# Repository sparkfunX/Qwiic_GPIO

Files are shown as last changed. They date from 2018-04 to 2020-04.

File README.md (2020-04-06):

SparkX Qwiic GPIO
=======================================

SparkX Qwiic GPIO (https://cdn.sparkfun.com/assets/parts/1/5/1/3/9/16406-Qwiic_GPIO-01.jpg)

[*SparkX Qwiic GPIO (SPX-16443)*](https://www.sparkfun.com/products/16443)

TCA9534 breakout board with Qwiic connectors and easy-to-use latch terminals; no longer screw wires into place! Use this board to add more GPIO pins to your system.

Repository Contents
-------------------

* **/Documents** - Contains datasheets and schematic.pdf
* **/Hardware** - Current .brd and .sch files for product
* **/Software** - Examples to get started with Qwiic GPIO

License Information
-------------------

This product is _**open source**_!

Please review the LICENSE.md file for license information.

If you have any questions or concerns on licensing, please contact technical support on our [SparkFun forums](https://forum.sparkfun.com/viewforum.php?f=152).

Distributed as-is; no warranty is given.

- Your friends at SparkFun.

_<COLLABORATION CREDIT>_

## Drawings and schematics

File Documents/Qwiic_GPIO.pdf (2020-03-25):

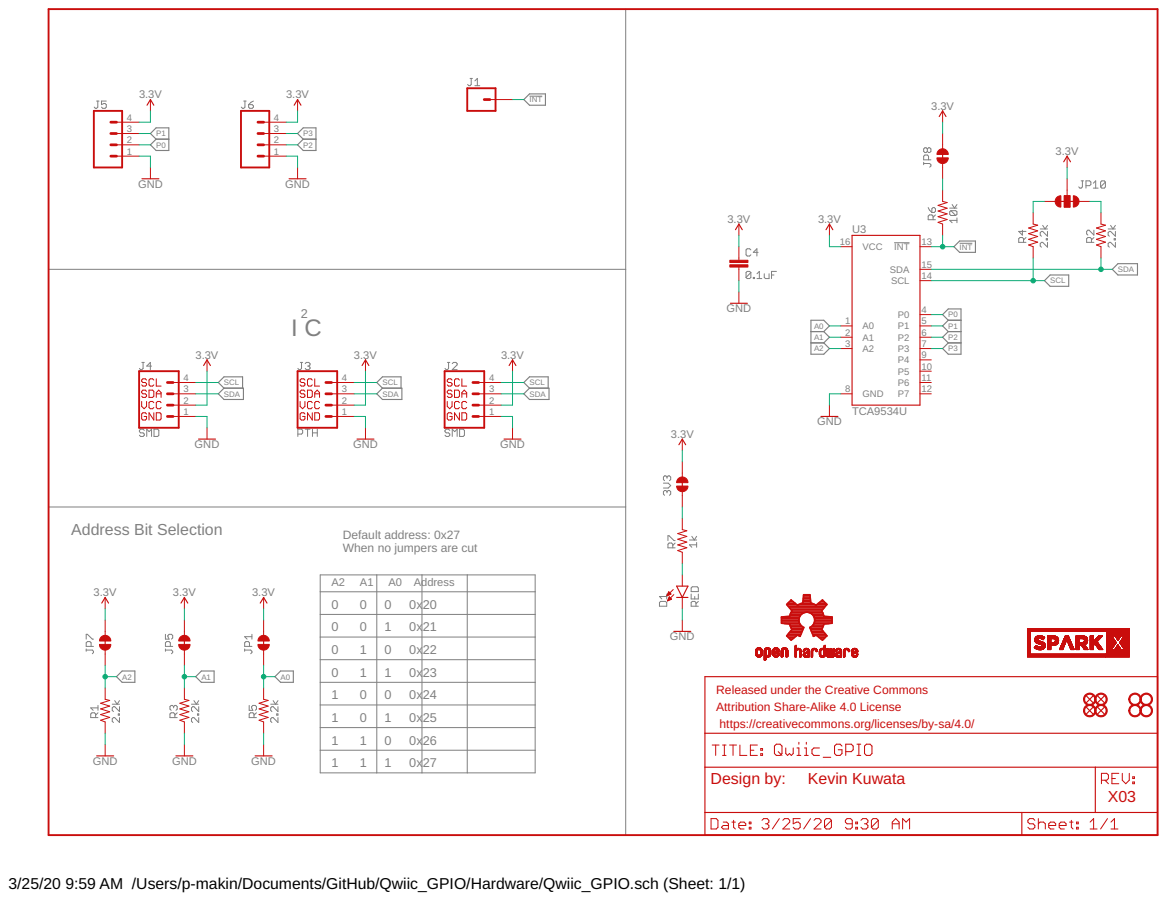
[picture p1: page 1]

Default address: 0x27
When no jumpers are cut

A2 A1 0 | 0 A0 Address 0 0x20

0 0 | 1 0x21
0 1 | 0 0x22
0 1 | 1 0x23
1 0 | 0 0x24
1 0 | 1 0x25
1 1 | 0 0x26
1 1 | 1 0x27

Released under the Creative Commons Attribution Share-Alike 4.0 License

https://creativecommons.org/licenses/by-sa/4.0/

3/25/20 9:59 AM /Users/p-makin/Documents/GitHub/Qwiic_GPIO/Hardware/Qwiic_GPIO.sch (Sheet: 1/1)

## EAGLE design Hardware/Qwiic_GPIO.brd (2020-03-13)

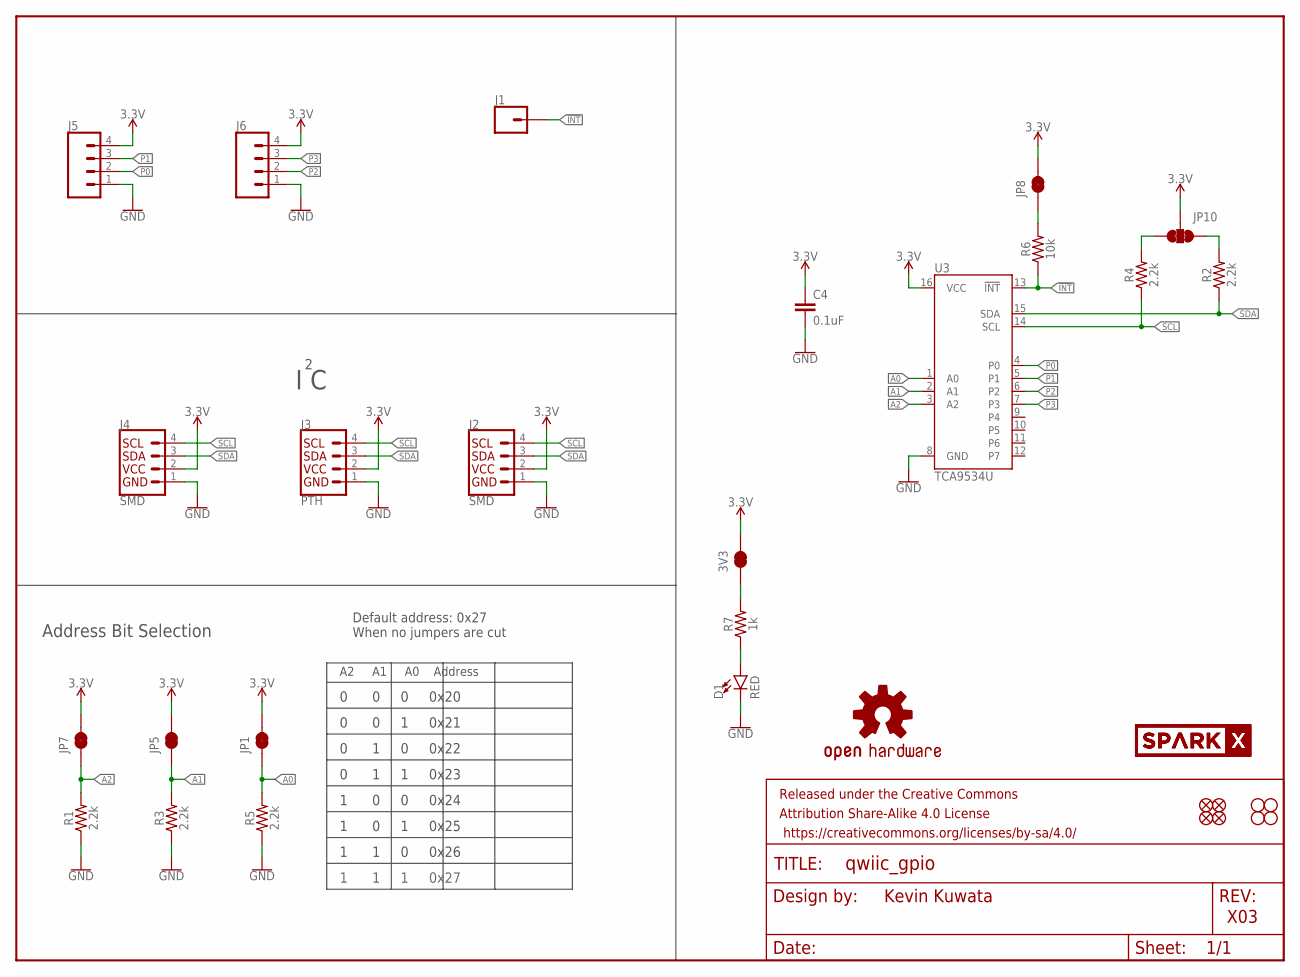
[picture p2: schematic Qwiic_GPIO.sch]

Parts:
3V3: JUMPER-SMT_2_NC_TRACE_SILK; SMT-JUMPER_2_NC_TRACE_SILK
C4: 0.1uF; 0603
D1: RED; LED-0603
FD1, FD2: FIDUCIAL1X2; FIDUCIAL-1X2
FRAME1: FRAME-LETTER; CREATIVE_COMMONS
H1, H2: STAND-OFF
J1: CONN_01PTH_NO_SILK_YES_STOP; 1X01_NO_SILK
J2, J4: SMD; 1X04_1MM_RA
J3: PTH; 1X04_NO_SILK
J5, J6: CONN_04LATCH; LATCHTERMINAL-5MM-4
JP1, JP5, JP7, JP8: JUMPER-SMT_2_NC_TRACE_SILK; SMT-JUMPER_2_NC_TRACE_SILK
JP2, JP6: FIDUCIAL1X2; FIDUCIAL-1X2
JP3, JP4: STAND-OFF
JP10: JUMPER-SMT_3_2-NC_TRACE_SILK; SMT-JUMPER_3_2-NC_TRACE_SILK
LOGO1: OSHW-LOGOMINI; OSHW-LOGO-MINI
R1, R2, R3, R4, R5: 2.2k; 0603
R6: 10k; 0603
R7: 1k; 0603
U3: TCA9534U; 16SOIC
U$1, U$2: SPARKX-LOGO3; SPARKX-SMALL

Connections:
3.3V: 3V3.2, C4.1, J2.2 (VCC), J3.2 (VCC), J4.2 (VCC), J5.4, J6.4, JP1.2, JP5.2, JP7.2, JP8.2, JP10.2, U3.16 (VCC)
!INT: J1.1, R6.1, U3.13 (!INT)
A0: JP1.1, R5.2, U3.1 (A0)
A1: JP5.1, R3.2, U3.2 (A1)
A2: JP7.1, R1.2, U3.3 (A2)
GND: C4.2, D1.C, J2.1 (GND), J3.1 (GND), J4.1 (GND), J5.1, J6.1, R1.1, R3.1, R5.1, U3.8 (GND)
unnamed: JP8.1, R6.2
unnamed: D1.A, R7.1
unnamed: 3V3.1, R7.2
P0: J5.2, U3.4 (P0)
P1: J5.3, U3.5 (P1)
P2: J6.2, U3.6 (P2)
P3: J6.3, U3.7 (P3)
SCL: J2.4 (SCL), J3.4 (SCL), J4.4 (SCL), R4.1, U3.14 (SCL)
SCL_PU1: JP10.1, R2.2
SDA: J2.3 (SDA), J3.3 (SDA), J4.3 (SDA), R2.1, U3.15 (SDA)
SDA_PU1: JP10.3, R4.2

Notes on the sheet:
Kevin Kuwata
X03
I C
Address Bit Selection
A2 A1 A0 Address
0 0 0 0x20
0 0 1 0x21
0 1 0 0x22
0 1 1 0x23
1 0 0 0x24
1 0 1 0x25
1 1 0 0x26
1 1 1 0x27
Default address: 0x27 When no jumpers are cut

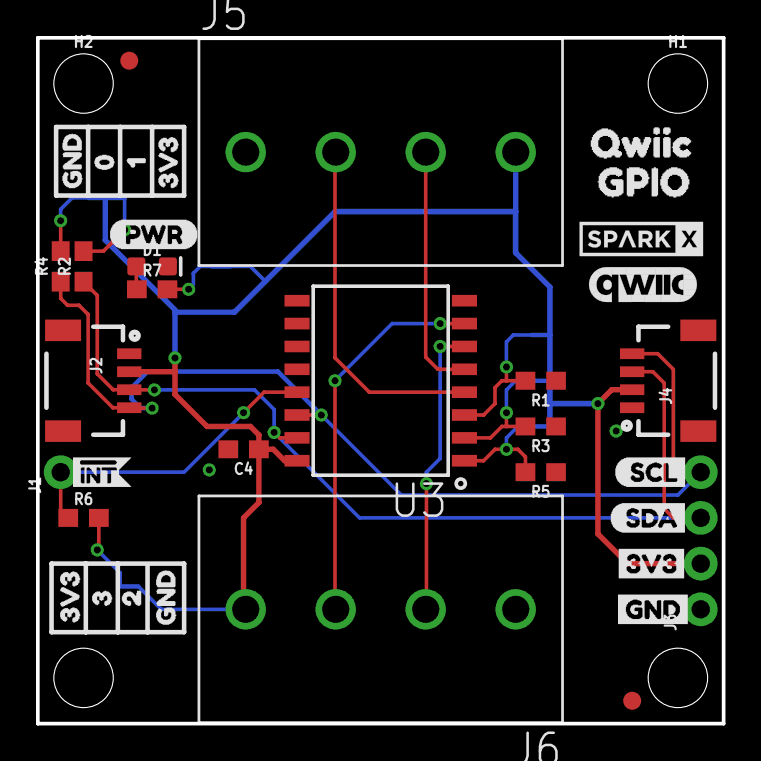
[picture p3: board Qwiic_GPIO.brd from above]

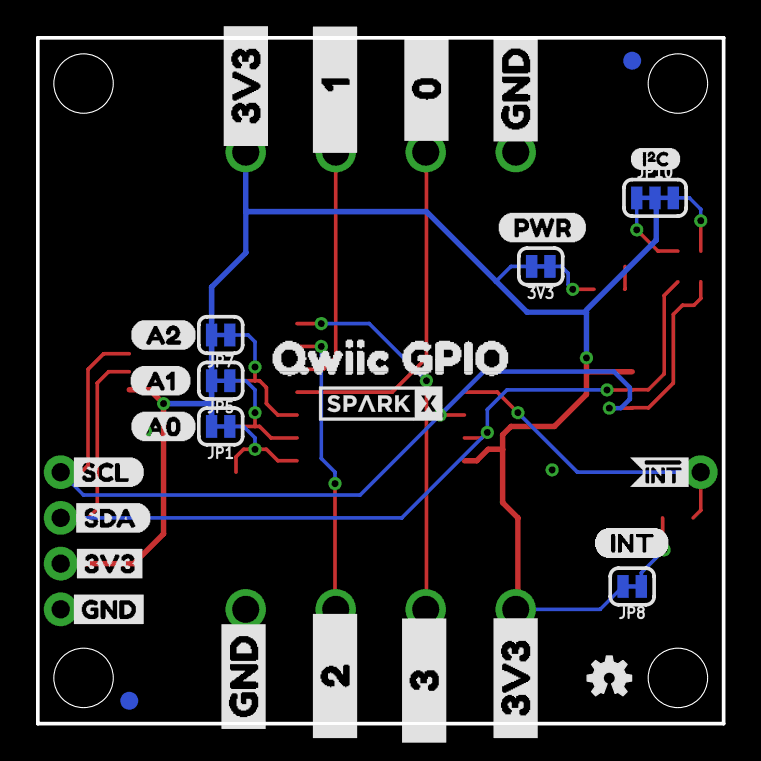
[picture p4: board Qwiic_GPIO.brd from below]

Board: 2 copper layers, 38.1 x 38.1 mm, 72 parts (31 on the bottom side), 17 nets.

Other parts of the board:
U$3, U$26, U$38: 3V33
U$5: A11
U$7, U$25: GND4
U$8: QWIIC_GPIO7
U$9: SCL6
U$10: SDA5
U$11: A00
U$12: A21
U$13, U$22: #INT0
U$20: I_SUPER2_C-()-03
U$21: QWIIC_6MM
U$23: SCL0
U$24: SDA1
U$27: 3V32
U$28: GND1
U$29: 15
U$30, U$31: INT1
U$32: QWIIC1
U$33: 20
U$34: 31
U$35: GND2
U$36: GPIO1
U$37: 04
U$39, U$40: PWR0
U$41: ____0____1
U$42: ____2____3
U$43: ____3____4
U$44: _____1____2
U$45, U$46: GND0
U$47, U$48: _3V3_0

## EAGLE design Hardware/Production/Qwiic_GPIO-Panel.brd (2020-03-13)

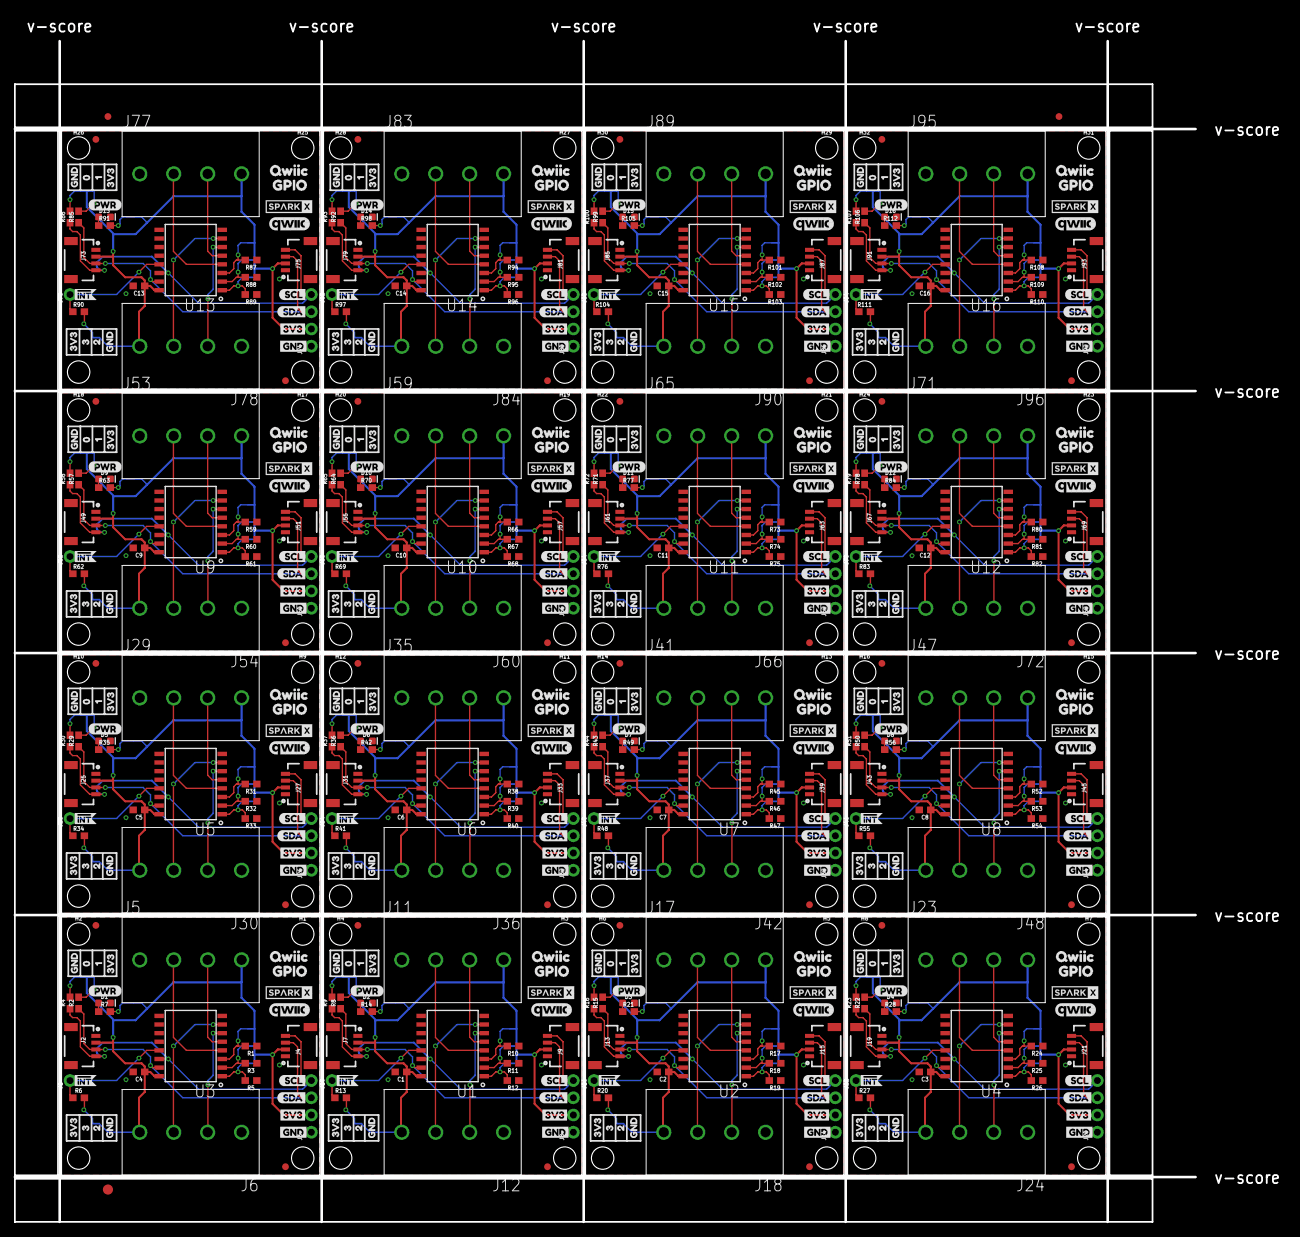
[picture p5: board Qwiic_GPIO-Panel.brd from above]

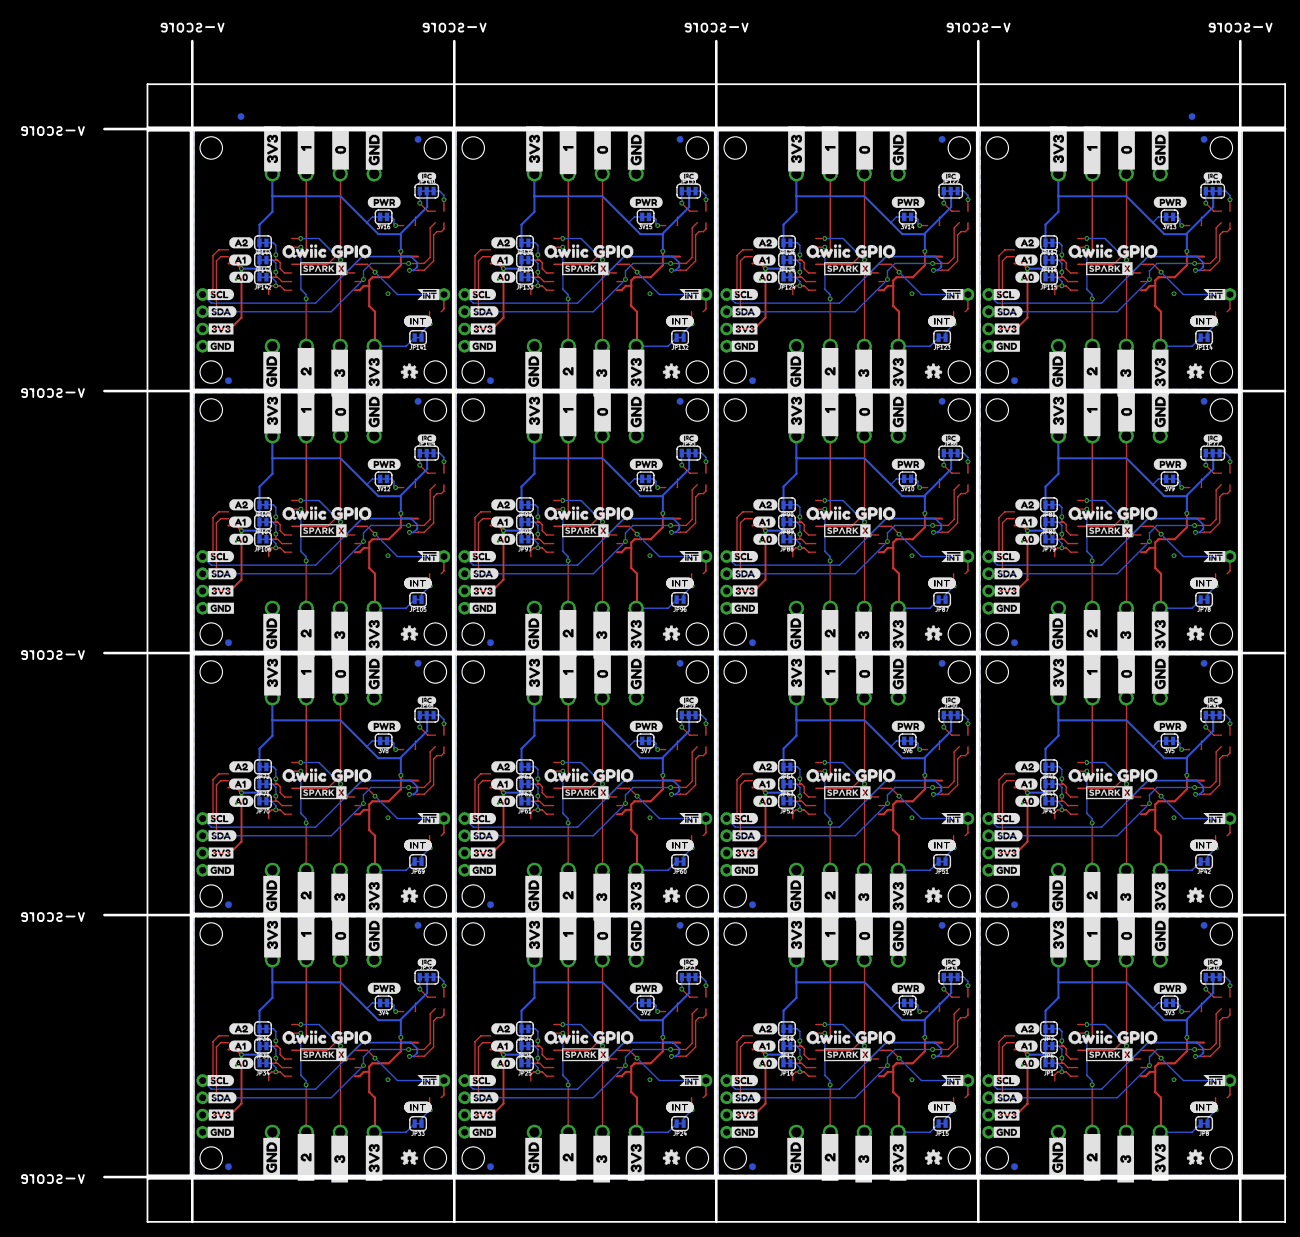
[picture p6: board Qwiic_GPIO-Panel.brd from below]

Board: 2 copper layers, 174.0 x 174.0 mm, 1141 parts (498 on the bottom side), 272 nets.

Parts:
3V1, 3V2, 3V3, 3V4, 3V5, 3V6, 3V7, 3V8, 3V9, 3V10, 3V11, 3V12, 3V13, 3V14, 3V15, 3V16: JUMPER-SMT_2_NC_TRACE_SILK; SMT-JUMPER_2_NC_TRACE_SILK
C1, C2, C3, C4, C5, C6, C7, C8, C9, C10, C11, C12, C13, C14, C15, C16: 0.1uF; 0603
D1, D2, D3, D4, D5, D6, D7, D8, D9, D10, D11, D12, D13, D14, D15, D16: RED; LED-0603
E$1, E$2, E$3, E$4: FIDUCIAL-1X2
E$5: FIDUCIAL-1.5X3
FD1, FD2, FD3, FD4, FD5, FD6, FD7, FD8, FD9, FD10, FD11, FD12, FD13, FD14, FD15, FD16, FD17, FD18, FD19, FD20, FD21, FD22, FD23, FD24, FD25, FD26, FD27, FD28, FD29, FD30, FD31, FD32: FIDUCIAL1X2; FIDUCIAL-1X2
H1, H2, H3, H4, H5, H6, H7, H8, H9, H10, H11, H12, H13, H14, H15, H16, H17, H18, H19, H20, H21, H22, H23, H24, H25, H26, H27, H28, H29, H30, H31, H32: STAND-OFF
J1, J10, J16, J22, J28, J34, J40, J46, J52, J58, J64, J70, J76, J82, J88, J94: 1X01_NO_SILK
J2, J4, J7, J9, J13, J15, J19, J21, J25, J27, J31, J33, J37, J39, J43, J45, J49, J51, J55, J57, J61, J63, J67, J69, J73, J75, J79, J81, J85, J87, J91, J93: SMD; 1X04_1MM_RA
J3, J8, J14, J20, J26, J32, J38, J44, J50, J56, J62, J68, J74, J80, J86, J92: PTH; 1X04_NO_SILK
J5, J6, J11, J12, J17, J18, J23, J24, J29, J30, J35, J36, J41, J42, J47, J48, J53, J54, J59, J60, J65, J66, J71, J72, J77, J78, J83, J84, J89, J90, J95, J96: LATCHTERMINAL-5MM-4
JP1, JP5, JP7, JP16, JP17, JP18, JP25, JP26, JP27, JP34, JP35, JP36, JP43, JP44, JP45, JP52, JP53, JP54, JP61, JP62, JP63, JP70, JP71, JP72, JP79, JP80, JP81, JP88, JP89, JP90, JP97, JP98, JP99, JP106, JP107, JP108, JP115, JP116, JP117, JP124, JP125, JP126, JP133, JP134, JP135, JP142, JP143, JP144: SMT-JUMPER_2_NC_TRACE_SILK
JP2, JP6, JP12, JP13, JP21, JP22, JP30, JP31, JP39, JP40, JP48, JP49, JP57, JP58, JP66, JP67, JP75, JP76, JP84, JP85, JP93, JP94, JP102, JP103, JP111, JP112, JP120, JP121, JP129, JP130, JP138, JP139: FIDUCIAL1X2; FIDUCIAL-1X2
JP3, JP4, JP9, JP11, JP19, JP20, JP28, JP29, JP37, JP38, JP46, JP47, JP55, JP56, JP64, JP65, JP73, JP74, JP82, JP83, JP91, JP92, JP100, JP101, JP109, JP110, JP118, JP119, JP127, JP128, JP136, JP137: STAND-OFF
JP8, JP15, JP24, JP33, JP42, JP51, JP60, JP69, JP78, JP87, JP96, JP105, JP114, JP123, JP132, JP141: JUMPER-SMT_2_NC_TRACE_SILK; SMT-JUMPER_2_NC_TRACE_SILK
JP10, JP14, JP23, JP32, JP41, JP50, JP59, JP68, JP77, JP86, JP95, JP104, JP113, JP122, JP131, JP140: JUMPER-SMT_3_2-NC_TRACE_SILK; SMT-JUMPER_3_2-NC_TRACE_SILK
LOGO1, LOGO2, LOGO3, LOGO4, LOGO5, LOGO6, LOGO7, LOGO8, LOGO9, LOGO10, LOGO11, LOGO12, LOGO13, LOGO14, LOGO15, LOGO16: OSHW-LOGOMINI; OSHW-LOGO-MINI
R1, R2, R3, R4, R5, R8, R9, R10, R11, R12, R15, R16, R17, R18, R19, R22, R23, R24, R25, R26, R29, R30, R31, R32, R33, R36, R37, R38, R39, R40, R43, R44, R45, R46, R47, R50, R51, R52, R53, R54, R57, R58, R59, R60, R61, R64, R65, R66, R67, R68, R71, R72, R73, R74, R75, R78, R79, R80, R81, R82, R85, R86, R87, R88, R89, R92, R93, R94, R95, R96, R99, R100, R101, R102, R103, R106, R107, R108, R109, R110: 2.2k; 0603
R6, R13, R20, R27, R34, R41, R48, R55, R62, R69, R76, R83, R90, R97, R104, R111: 10k; 0603
R7, R14, R21, R28, R35, R42, R49, R56, R63, R70, R77, R84, R91, R98, R105, R112: 1k; 0603
U1, U2, U3, U4, U5, U6, U7, U8, U9, U10, U11, U12, U13, U14, U15, U16: TCA9534U; 16SOIC
U$1, U$2, U$4, U$6, U$81, U$82, U$121, U$122, U$161, U$162, U$201, U$202, U$241, U$242, U$281, U$282, U$321, U$322, U$361, U$362, U$401, U$402, U$441, U$442, U$481, U$482, U$521, U$522, U$561, U$562, U$601, U$602: SPARKX-LOGO3; SPARKX-SMALL
U$3, U$14, U$26, U$38, U$56, U$66, U$83, U$96, U$106, U$123, U$136, U$146, U$163, U$176, U$186, U$203, U$216, U$226, U$243, U$256, U$266, U$283, U$296, U$306, U$323, U$336, U$346, U$363, U$376, U$386, U$403, U$416, U$426, U$443, U$456, U$466, U$483, U$496, U$506, U$523, U$536, U$546, U$563, U$576, U$586, U$603, U$616, U$626: 3V33
U$5, U$15, U$84, U$124, U$164, U$204, U$244, U$284, U$324, U$364, U$404, U$444, U$484, U$524, U$564, U$604: A11
U$7, U$16, U$25, U$55, U$85, U$95, U$125, U$135, U$165, U$175, U$205, U$215, U$245, U$255, U$285, U$295, U$325, U$335, U$365, U$375, U$405, U$415, U$445, U$455, U$485, U$495, U$525, U$535, U$565, U$575, U$605, U$615: GND4
U$8, U$17, U$86, U$126, U$166, U$206, U$246, U$286, U$326, U$366, U$406, U$446, U$486, U$526, U$566, U$606: QWIIC_GPIO7
U$9, U$18, U$87, U$127, U$167, U$207, U$247, U$287, U$327, U$367, U$407, U$447, U$487, U$527, U$567, U$607: SCL6
U$10, U$19, U$88, U$128, U$168, U$208, U$248, U$288, U$328, U$368, U$408, U$448, U$488, U$528, U$568, U$608: SDA5
U$11, U$49, U$89, U$129, U$169, U$209, U$249, U$289, U$329, U$369, U$409, U$449, U$489, U$529, U$569, U$609: A00
U$12, U$50, U$90, U$130, U$170, U$210, U$250, U$290, U$330, U$370, U$410, U$450, U$490, U$530, U$570, U$610: A21
U$13, U$22, U$57, U$58, U$97, U$98, U$137, U$138, U$177, U$178, U$217, U$218, U$257, U$258, U$297, U$298, U$337, U$338, U$377, U$378, U$417, U$418, U$457, U$458, U$497, U$498, U$537, U$538, U$577, U$578, U$617, U$618: #INT0
U$20, U$51, U$91, U$131, U$171, U$211, U$251, U$291, U$331, U$371, U$411, U$451, U$491, U$531, U$571, U$611: I_SUPER2_C-()-03
U$21, U$52, U$92, U$132, U$172, U$212, U$252, U$292, U$332, U$372, U$412, U$452, U$492, U$532, U$572, U$612: QWIIC_6MM
U$23, U$53, U$93, U$133, U$173, U$213, U$253, U$293, U$333, U$373, U$413, U$453, U$493, U$533, U$573, U$613: SCL0
U$24, U$54, U$94, U$134, U$174, U$214, U$254, U$294, U$334, U$374, U$414, U$454, U$494, U$534, U$574, U$614: SDA1
U$27, U$67, U$107, U$147, U$187, U$227, U$267, U$307, U$347, U$387, U$427, U$467, U$507, U$547, U$587, U$627: 3V32
U$28, U$68, U$108, U$148, U$188, U$228, U$268, U$308, U$348, U$388, U$428, U$468, U$508, U$548, U$588, U$628: GND1
U$29, U$62, U$102, U$142, U$182, U$222, U$262, U$302, U$342, U$382, U$422, U$462, U$502, U$542, U$582, U$622: 15
U$30, U$31, U$69, U$70, U$109, U$110, U$149, U$150, U$189, U$190, U$229, U$230, U$269, U$270, U$309, U$310, U$349, U$350, U$389, U$390, U$429, U$430, U$469, U$470, U$509, U$510, U$549, U$550, U$589, U$590, U$629, U$630: INT1
U$32, U$59, U$99, U$139, U$179, U$219, U$259, U$299, U$339, U$379, U$419, U$459, U$499, U$539, U$579, U$619: QWIIC1
U$33, U$63, U$103, U$143, U$183, U$223, U$263, U$303, U$343, U$383, U$423, U$463, U$503, U$543, U$583, U$623: 20
U$34, U$64, U$104, U$144, U$184, U$224, U$264, U$304, U$344, U$384, U$424, U$464, U$504, U$544, U$584, U$624: 31
U$35, U$65, U$105, U$145, U$185, U$225, U$265, U$305, U$345, U$385, U$425, U$465, U$505, U$545, U$585, U$625: GND2
U$36, U$60, U$100, U$140, U$180, U$220, U$260, U$300, U$340, U$380, U$420, U$460, U$500, U$540, U$580, U$620: GPIO1
U$37, U$61, U$101, U$141, U$181, U$221, U$261, U$301, U$341, U$381, U$421, U$461, U$501, U$541, U$581, U$621: 04
U$39, U$40, U$71, U$72, U$111, U$112, U$151, U$152, U$191, U$192, U$231, U$232, U$271, U$272, U$311, U$312, U$351, U$352, U$391, U$392, U$431, U$432, U$471, U$472, U$511, U$512, U$551, U$552, U$591, U$592, U$631, U$632: PWR0
U$41, U$73, U$113, U$153, U$193, U$233, U$273, U$313, U$353, U$393, U$433, U$473, U$513, U$553, U$593, U$633: ____0____1
U$42, U$74, U$114, U$154, U$194, U$234, U$274, U$314, U$354, U$394, U$434, U$474, U$514, U$554, U$594, U$634: ____2____3
U$43, U$75, U$115, U$155, U$195, U$235, U$275, U$315, U$355, U$395, U$435, U$475, U$515, U$555, U$595, U$635: ____3____4
U$44, U$76, U$116, U$156, U$196, U$236, U$276, U$316, U$356, U$396, U$436, U$476, U$516, U$556, U$596, U$636: _____1____2
U$45, U$46, U$77, U$78, U$117, U$118, U$157, U$158, U$197, U$198, U$237, U$238, U$277, U$278, U$317, U$318, U$357, U$358, U$397, U$398, U$437, U$438, U$477, U$478, U$517, U$518, U$557, U$558, U$597, U$598, U$637, U$638: GND0
U$47, U$48, U$79, U$80, U$119, U$120, U$159, U$160, U$199, U$200, U$239, U$240, U$279, U$280, U$319, U$320, U$359, U$360, U$399, U$400, U$439, U$440, U$479, U$480, U$519, U$520, U$559, U$560, U$599, U$600, U$639, U$640: _3V3_0

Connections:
3.3V: 3V3.2, C4.1, J2.2, J3.2, J4.2, J5.4, J6.4, JP1.2, JP5.2, JP7.2, JP8.2, JP10.2, U3.16
3.3V1: 3V1.2, C1.1, J7.2, J8.2, J9.2, J11.4, J12.4, JP14.2, JP15.2, JP16.2, JP17.2, JP18.2, U1.16
3.3V2: 3V2.2, C2.1, J13.2, J14.2, J15.2, J17.4, J18.4, JP23.2, JP24.2, JP25.2, JP26.2, JP27.2, U2.16
3.3V3: 3V4.2, C3.1, J19.2, J20.2, J21.2, J23.4, J24.4, JP32.2, JP33.2, JP34.2, JP35.2, JP36.2, U4.16
3.3V4: 3V5.2, C5.1, J25.2, J26.2, J27.2, J29.4, J30.4, JP41.2, JP42.2, JP43.2, JP44.2, JP45.2, U5.16
3.3V5: 3V6.2, C6.1, J31.2, J32.2, J33.2, J35.4, J36.4, JP50.2, JP51.2, JP52.2, JP53.2, JP54.2, U6.16
3.3V6: 3V7.2, C7.1, J37.2, J38.2, J39.2, J41.4, J42.4, JP59.2, JP60.2, JP61.2, JP62.2, JP63.2, U7.16
3.3V7: 3V8.2, C8.1, J43.2, J44.2, J45.2, J47.4, J48.4, JP68.2, JP69.2, JP70.2, JP71.2, JP72.2, U8.16
3.3V8: 3V9.2, C9.1, J49.2, J50.2, J51.2, J53.4, J54.4, JP77.2, JP78.2, JP79.2, JP80.2, JP81.2, U9.16
3.3V9: 3V10.2, C10.1, J55.2, J56.2, J57.2, J59.4, J60.4, JP86.2, JP87.2, JP88.2, JP89.2, JP90.2, U10.16
3.3V10: 3V11.2, C11.1, J61.2, J62.2, J63.2, J65.4, J66.4, JP95.2, JP96.2, JP97.2, JP98.2, JP99.2, U11.16
3.3V11: 3V12.2, C12.1, J67.2, J68.2, J69.2, J71.4, J72.4, JP104.2, JP105.2, JP106.2, JP107.2, JP108.2, U12.16
3.3V12: 3V13.2, C13.1, J73.2, J74.2, J75.2, J77.4, J78.4, JP113.2, JP114.2, JP115.2, JP116.2, JP117.2, U13.16
3.3V13: 3V14.2, C14.1, J79.2, J80.2, J81.2, J83.4, J84.4, JP122.2, JP123.2, JP124.2, JP125.2, JP126.2, U14.16
3.3V14: 3V15.2, C15.1, J85.2, J86.2, J87.2, J89.4, J90.4, JP131.2, JP132.2, JP133.2, JP134.2, JP135.2, U15.16
3.3V15: 3V16.2, C16.1, J91.2, J92.2, J93.2, J95.4, J96.4, JP140.2, JP141.2, JP142.2, JP143.2, JP144.2, U16.16
!INT: J1.1, R6.1, U3.13
!INT1: J10.1, R13.1, U1.13
!INT2: J16.1, R20.1, U2.13
!INT3: J22.1, R27.1, U4.13
!INT4: J28.1, R34.1, U5.13
!INT5: J34.1, R41.1, U6.13
!INT6: J40.1, R48.1, U7.13
!INT7: J46.1, R55.1, U8.13
!INT8: J52.1, R62.1, U9.13
!INT9: J58.1, R69.1, U10.13
!INT10: J64.1, R76.1, U11.13
!INT11: J70.1, R83.1, U12.13
!INT12: J76.1, R90.1, U13.13
!INT13: J82.1, R97.1, U14.13
!INT14: J88.1, R104.1, U15.13
!INT15: J94.1, R111.1, U16.13
A0: JP1.1, R5.2, U3.1
A1: JP5.1, R3.2, U3.2
A2: JP7.1, R1.2, U3.3
A3: JP16.1, R12.2, U1.1
A4: JP17.1, R11.2, U1.2
A5: JP18.1, R10.2, U1.3
A6: JP25.1, R19.2, U2.1
A7: JP26.1, R18.2, U2.2
A8: JP27.1, R17.2, U2.3
A9: JP34.1, R26.2, U4.1
A10: JP35.1, R25.2, U4.2
A11: JP36.1, R24.2, U4.3
A12: JP43.1, R33.2, U5.1
A13: JP44.1, R32.2, U5.2
A14: JP45.1, R31.2, U5.3
A15: JP52.1, R40.2, U6.1
A16: JP53.1, R39.2, U6.2
A17: JP54.1, R38.2, U6.3
A18: JP61.1, R47.2, U7.1
A19: JP62.1, R46.2, U7.2
A20: JP63.1, R45.2, U7.3
A21: JP70.1, R54.2, U8.1
A22: JP71.1, R53.2, U8.2
A23: JP72.1, R52.2, U8.3
A24: JP79.1, R61.2, U9.1
A25: JP80.1, R60.2, U9.2
A26: JP81.1, R59.2, U9.3
A27: JP88.1, R68.2, U10.1
A28: JP89.1, R67.2, U10.2
A29: JP90.1, R66.2, U10.3
A30: JP97.1, R75.2, U11.1
A31: JP98.1, R74.2, U11.2
A32: JP99.1, R73.2, U11.3
A33: JP106.1, R82.2, U12.1
A34: JP107.1, R81.2, U12.2
A35: JP108.1, R80.2, U12.3
A36: JP115.1, R89.2, U13.1
A37: JP116.1, R88.2, U13.2
A38: JP117.1, R87.2, U13.3
A39: JP124.1, R96.2, U14.1
A40: JP125.1, R95.2, U14.2
A41: JP126.1, R94.2, U14.3
A42: JP133.1, R103.2, U15.1
A43: JP134.1, R102.2, U15.2
A44: JP135.1, R101.2, U15.3
A45: JP142.1, R110.2, U16.1
A46: JP143.1, R109.2, U16.2
A47: JP144.1, R108.2, U16.3
GND: C4.2, D1.C, J2.1, J3.1, J4.1, J5.1, J6.1, R1.1, R3.1, R5.1, U3.8
GND1: C1.2, D2.C, J7.1, J8.1, J9.1, J11.1, J12.1, R10.1, R11.1, R12.1, U1.8
GND2: C2.2, D3.C, J13.1, J14.1, J15.1, J17.1, J18.1, R17.1, R18.1, R19.1, U2.8
GND3: C3.2, D4.C, J19.1, J20.1, J21.1, J23.1, J24.1, R24.1, R25.1, R26.1, U4.8
GND4: C5.2, D5.C, J25.1, J26.1, J27.1, J29.1, J30.1, R31.1, R32.1, R33.1, U5.8
GND5: C6.2, D6.C, J31.1, J32.1, J33.1, J35.1, J36.1, R38.1, R39.1, R40.1, U6.8
GND6: C7.2, D7.C, J37.1, J38.1, J39.1, J41.1, J42.1, R45.1, R46.1, R47.1, U7.8
GND7: C8.2, D8.C, J43.1, J44.1, J45.1, J47.1, J48.1, R52.1, R53.1, R54.1, U8.8
GND8: C9.2, D9.C, J49.1, J50.1, J51.1, J53.1, J54.1, R59.1, R60.1, R61.1, U9.8
GND9: C10.2, D10.C, J55.1, J56.1, J57.1, J59.1, J60.1, R66.1, R67.1, R68.1, U10.8
GND10: C11.2, D11.C, J61.1, J62.1, J63.1, J65.1, J66.1, R73.1, R74.1, R75.1, U11.8
GND11: C12.2, D12.C, J67.1, J68.1, J69.1, J71.1, J72.1, R80.1, R81.1, R82.1, U12.8
GND12: C13.2, D13.C, J73.1, J74.1, J75.1, J77.1, J78.1, R87.1, R88.1, R89.1, U13.8
GND13: C14.2, D14.C, J79.1, J80.1, J81.1, J83.1, J84.1, R94.1, R95.1, R96.1, U14.8
GND14: C15.2, D15.C, J85.1, J86.1, J87.1, J89.1, J90.1, R101.1, R102.1, R103.1, U15.8
GND15: C16.2, D16.C, J91.1, J92.1, J93.1, J95.1, J96.1, R108.1, R109.1, R110.1, U16.8
unnamed: JP8.1, R6.2
unnamed: D1.A, R7.1
unnamed: 3V3.1, R7.2
unnamed: JP15.1, R13.2
unnamed: D2.A, R14.1
unnamed: 3V1.1, R14.2
unnamed: JP24.1, R20.2
unnamed: D3.A, R21.1
unnamed: 3V2.1, R21.2
unnamed: JP33.1, R27.2
unnamed: D4.A, R28.1
unnamed: 3V4.1, R28.2
unnamed: JP42.1, R34.2
unnamed: D5.A, R35.1
unnamed: 3V5.1, R35.2
unnamed: JP51.1, R41.2
unnamed: D6.A, R42.1
unnamed: 3V6.1, R42.2
unnamed: JP60.1, R48.2
unnamed: D7.A, R49.1
unnamed: 3V7.1, R49.2
unnamed: JP69.1, R55.2
unnamed: D8.A, R56.1
unnamed: 3V8.1, R56.2
unnamed: JP78.1, R62.2
unnamed: D9.A, R63.1
unnamed: 3V9.1, R63.2
unnamed: JP87.1, R69.2
unnamed: D10.A, R70.1
unnamed: 3V10.1, R70.2
unnamed: JP96.1, R76.2
unnamed: D11.A, R77.1
unnamed: 3V11.1, R77.2
unnamed: JP105.1, R83.2
unnamed: D12.A, R84.1
unnamed: 3V12.1, R84.2
unnamed: JP114.1, R90.2
unnamed: D13.A, R91.1
unnamed: 3V13.1, R91.2
unnamed: JP123.1, R97.2
unnamed: D14.A, R98.1
unnamed: 3V14.1, R98.2
unnamed: JP132.1, R104.2
unnamed: D15.A, R105.1
unnamed: 3V15.1, R105.2
unnamed: JP141.1, R111.2
unnamed: D16.A, R112.1
unnamed: 3V16.1, R112.2
P0: J5.2, U3.4
P1: J5.3, U3.5
P2: J6.2, U3.6
P3: J6.3, U3.7
P4: J11.2, U1.4
P5: J12.2, U1.6
P6: J12.3, U1.7
P7: J11.3, U1.5
P8: J17.2, U2.4
P9: J18.2, U2.6
P10: J18.3, U2.7
P11: J17.3, U2.5
P12: J23.2, U4.4
P13: J24.2, U4.6
P14: J24.3, U4.7
P15: J23.3, U4.5
P16: J29.2, U5.4
P17: J30.2, U5.6
P18: J30.3, U5.7
P19: J29.3, U5.5
P20: J35.2, U6.4
P21: J36.2, U6.6
P22: J36.3, U6.7
P23: J35.3, U6.5
P24: J41.2, U7.4
P25: J42.2, U7.6
P26: J42.3, U7.7
P27: J41.3, U7.5
P28: J47.2, U8.4
P29: J48.2, U8.6
P30: J48.3, U8.7
P31: J47.3, U8.5
P32: J53.2, U9.4
P33: J54.2, U9.6
P34: J54.3, U9.7
P35: J53.3, U9.5
P36: J59.2, U10.4
P37: J60.2, U10.6
P38: J60.3, U10.7
P39: J59.3, U10.5
P40: J65.2, U11.4
P41: J66.2, U11.6
P42: J66.3, U11.7
P43: J65.3, U11.5
P44: J71.2, U12.4
P45: J72.2, U12.6
P46: J72.3, U12.7
P47: J71.3, U12.5
P48: J77.2, U13.4
P49: J78.2, U13.6
P50: J78.3, U13.7
P51: J77.3, U13.5
P52: J83.2, U14.4
P53: J84.2, U14.6
P54: J84.3, U14.7
P55: J83.3, U14.5
P56: J89.2, U15.4
P57: J90.2, U15.6
P58: J90.3, U15.7
P59: J89.3, U15.5
P60: J95.2, U16.4
P61: J96.2, U16.6
P62: J96.3, U16.7
P63: J95.3, U16.5
SCL: J2.4, J3.4, J4.4, R4.1, U3.14
SCL1: J7.4, J8.4, J9.4, R9.1, U1.14
SCL2: J13.4, J14.4, J15.4, R16.1, U2.14
SCL3: J19.4, J20.4, J21.4, R23.1, U4.14
SCL4: J25.4, J26.4, J27.4, R30.1, U5.14
SCL5: J31.4, J32.4, J33.4, R37.1, U6.14
SCL6: J37.4, J38.4, J39.4, R44.1, U7.14
SCL7: J43.4, J44.4, J45.4, R51.1, U8.14
SCL8: J49.4, J50.4, J51.4, R58.1, U9.14
SCL9: J55.4, J56.4, J57.4, R65.1, U10.14
SCL10: J61.4, J62.4, J63.4, R72.1, U11.14
SCL11: J67.4, J68.4, J69.4, R79.1, U12.14
SCL12: J73.4, J74.4, J75.4, R86.1, U13.14
SCL13: J79.4, J80.4, J81.4, R93.1, U14.14
SCL14: J85.4, J86.4, J87.4, R100.1, U15.14
SCL15: J91.4, J92.4, J93.4, R107.1, U16.14
SCL_PU1: JP10.1, R2.2
SCL_PU2: JP14.1, R8.2
SCL_PU3: JP23.1, R15.2
SCL_PU4: JP32.1, R22.2
SCL_PU5: JP41.1, R29.2
SCL_PU6: JP50.1, R36.2
SCL_PU7: JP59.1, R43.2
SCL_PU8: JP68.1, R50.2
SCL_PU9: JP77.1, R57.2
SCL_PU10: JP86.1, R64.2
SCL_PU11: JP95.1, R71.2
SCL_PU12: JP104.1, R78.2
SCL_PU13: JP113.1, R85.2
SCL_PU14: JP122.1, R92.2
SCL_PU15: JP131.1, R99.2
SCL_PU16: JP140.1, R106.2
SDA: J2.3, J3.3, J4.3, R2.1, U3.15
SDA1: J7.3, J8.3, J9.3, R8.1, U1.15
SDA2: J13.3, J14.3, J15.3, R15.1, U2.15
SDA3: J19.3, J20.3, J21.3, R22.1, U4.15
SDA4: J25.3, J26.3, J27.3, R29.1, U5.15
SDA5: J31.3, J32.3, J33.3, R36.1, U6.15
SDA6: J37.3, J38.3, J39.3, R43.1, U7.15
SDA7: J43.3, J44.3, J45.3, R50.1, U8.15
SDA8: J49.3, J50.3, J51.3, R57.1, U9.15
SDA9: J55.3, J56.3, J57.3, R64.1, U10.15
SDA10: J61.3, J62.3, J63.3, R71.1, U11.15
SDA11: J67.3, J68.3, J69.3, R78.1, U12.15
SDA12: J73.3, J74.3, J75.3, R85.1, U13.15
SDA13: J79.3, J80.3, J81.3, R92.1, U14.15
SDA14: J85.3, J86.3, J87.3, R99.1, U15.15
SDA15: J91.3, J92.3, J93.3, R106.1, U16.15
SDA_PU1: JP10.3, R4.2
SDA_PU2: JP14.3, R9.2
SDA_PU3: JP23.3, R16.2
SDA_PU4: JP32.3, R23.2
SDA_PU5: JP41.3, R30.2
SDA_PU6: JP50.3, R37.2
SDA_PU7: JP59.3, R44.2
SDA_PU8: JP68.3, R51.2
SDA_PU9: JP77.3, R58.2
SDA_PU10: JP86.3, R65.2
SDA_PU11: JP95.3, R72.2
SDA_PU12: JP104.3, R79.2
SDA_PU13: JP113.3, R86.2
SDA_PU14: JP122.3, R93.2
SDA_PU15: JP131.3, R100.2
SDA_PU16: JP140.3, R107.2

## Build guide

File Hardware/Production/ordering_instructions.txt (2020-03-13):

panel size, 168x161mm
PCB thickness, 1.6mm
number of layers, 2
soldermask color, Black
silkscreen color, White
oz copper, 1oz
finish, HASL lead free
stencils, top+bottom
pcs per panel, 16
min trace width, 0.2032mm / 0.0080in
min drill size, 0.3810mm / 0.0150in

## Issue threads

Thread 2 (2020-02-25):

Need power LED on next rev (X03?)

pmakin-png, 2020-02-25:
Rev X02 is missing a power LED.

pmakin-png, 2020-02-25:
ALSO! Should a library be written for this product?

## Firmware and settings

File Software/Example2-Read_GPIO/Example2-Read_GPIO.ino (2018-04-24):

/******************************************************************************
  Qwiic Relay Example 2 - Read GPIO
  Kevin Kuwata @ SparkX
  April 17, 2018
  https://github.com/sparkfunX/Qwiic_GPIO
  Arduino 1.8.5

  This sketch sets up a GPIO 5 as an input and makes GPIO 1 an output. 
  
  When the GPIO 5 is read LOW, GPIO 1 is set to HIGH and when GPIO5 is read 
  HIGH GPIO 1 is set LOW. 
  
******************************************************************************/

#include <Wire.h>


/* I2C Command Byte Defines  */
#define REGISTER_INPUT_PORT           	0x00    //register 0 
#define REGISTER_OUTPUT_PORT          	0X01    //register 1
#define REGISTER_CONFIGURATION         	0X03    //register 3

byte const qwiicGpioAddress = 0x27; //When all jumpers are closed A0, A1, A2 

void setup(){
	  // put your setup code here, to run once:
	Serial.begin(9600);
	Serial.println("Qwiic GPIO Example 2- Read GPIO");
	Wire.begin();

	testForConnectivity();
	
	setPinMode(qwiicGpioAddress, 1, OUTPUT);
	setPinMode(qwiicGpioAddress, 7, INPUT);
	
	setPinOutput(qwiicGpioAddress, 1, HIGH);
}

byte pinStateChangeOccurred = 0;
void loop(){	
	while(readPin(qwiicGpioAddress, 7) == LOW){
		setPinOutput(qwiicGpioAddress, 1, HIGH);
		Serial.println("Button Pressed");
		delay(100);
		pinStateChangeOccurred = 1;
	}	
	
	if(pinStateChangeOccurred == 1){
	setPinOutput(qwiicGpioAddress, 1, LOW);
		pinStateChangeOccurred = 0;
	}
}

/* ============================================================ */


/*
	readPin(byte address, byte pin) reads the input state of the specified pin
	and returns the corresponding pin's state. 
	
	similar to digitalRead()
*/
byte readPin(byte address, byte pin){
	byte currentRegisterValue = readRegister( address, REGISTER_INPUT_PORT);
	if(currentRegisterValue & (1 << pin)){
	return HIGH;
	}
	return LOW;
}

/*
	setPinMode(byte address, byte pin, byte direction) sets a single pin
	as an input or an output and does not affect the other pins. The direction
	input parameter is either INPUT or OUTPUT.
	
		similar to pinMode()
*/
void setPinMode(byte address, byte pin, byte direction){
	byte currentPinDirection = readRegister(address, REGISTER_CONFIGURATION);
		pin = 1 <<pin;
		
  if(direction == INPUT || direction == INPUT_PULLUP ){
		currentPinDirection |= pin; // pin will come in correctly masked because of a define. 
  }
  else if(direction == OUTPUT){
		currentPinDirection &= ~(pin);  
  }
  		writeRegister(address, REGISTER_CONFIGURATION, currentPinDirection );
}

/* 
	testForConnectivity() Checks for an ACK from the Qwiic GPIO
	Returns true if an Qwiic GPIO is connected. 
*/
boolean testForConnectivity() {
  Wire.beginTransmission(qwiicGpioAddress);
  //check here for an ACK from the slave, if no ack don't allow change?
  if (Wire.endTransmission() != 0) {
    return false;
  }
  return true;
}



/*
	setPinOutput(byte address, byte pin, byte state) will set a pin as high or low
	
			similar to digitalWrite(pin, state)

*/
void setPinOutput(byte address, byte pin, byte state){	
	pin =  1<<pin;
	
	byte currentRegisterValue = readRegister(address, REGISTER_OUTPUT_PORT);
	
	if(state == LOW){ //INVERSE OF ARDUINO, but this will result in the same effect a user would expect. 
		currentRegisterValue |= pin;
	}
	else if(state == HIGH){
		currentRegisterValue &= ~pin;
	}
	writeRegister(address, REGISTER_OUTPUT_PORT, currentRegisterValue);
}

/*
	readRegister(byte address, byte registerToRead) will read the register 
	values of a given register at a given address.

	Inputs: address, register values
*/
byte readRegister(byte address, byte registerToRead){
	Wire.beginTransmission(address);
	Wire.write(registerToRead); 
	Wire.endTransmission(false);
	Wire.requestFrom(address, 1);
	
	byte currentRegisterValue = 0;
	
	byte count = 0;
	while(Wire.available() >0){
	if(count ==0){
		currentRegisterValue = Wire.read();
	}
		Wire.read(); // don't collect
		count++;
	}
	return currentRegisterValue;
}

/*
	writeRegister(byte address, byte registerToWrite, byte valueToWrite) writes the 
	value passed to a specific register at the Qwiic GPIO address.
	
	Note: when writing to a register a full 8 bits is written- overwriting any 
	previous state.
	
	Inputs: Qwiic Gpio Address, Register to write to, and Byte to write
*/

void writeRegister(byte address, byte registerToWrite, byte valueToWrite){
	Wire.beginTransmission(address);
	Wire.write(registerToWrite); 
	Wire.write(valueToWrite);
	Wire.endTransmission();
}

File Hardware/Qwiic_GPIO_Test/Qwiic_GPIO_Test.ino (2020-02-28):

/************************************************************************
 * Qwiic GPIO test sketch
 * 
 * Priyanka Makin @ SparkFun Electronics
 * Original Creation Date: February 28, 2020 
 ***********************************************************************/
#include <Wire.h>

byte const qwiicGpioAddress = 0x27; //When all jumpers are closed A0, A1, A2
const int LED = 13;

void setup()
{
  Serial.begin(115200);
  Serial.println("Qwiic GPIO test sketch");

  Wire.begin();

  pinMode(LED, OUTPUT);
}

void loop()
{
 if (testForConnectivity() == true)
 {
  Serial.println("Qwiic GPIO connected.");
  digitalWrite(LED, HIGH); 
 }
 else
 {
  Serial.println("Nothing detected.");
  digitalWrite(LED, LOW);
 }
 delay(10);
}

boolean testForConnectivity() {
  Wire.beginTransmission(qwiicGpioAddress);
  //check here for an ACK from the slave
  if (Wire.endTransmission() != 0){
    return false;
  }
  return true;
}

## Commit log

2018-02-26 fixing silk, move resistors from mounting holes
    [Qwiic_TCA9534.sch]
2018-02-26 partial route
    [Qwiic_TCA9534.brd, Qwiic_TCA9534.sch]
2018-02-26 route complete
    [Qwiic_TCA9534.brd]
2018-04-11 starting to build out example 1
    example 1 is to set a pin on the expander as output or input, then set it as high or low. currently the setPinMode() function works, next is to make a 'digitalWrite' equivalent
    [Qwiic_TCA9534-Panel.GBL, Qwiic_TCA9534-Panel.GBO, Qwiic_TCA9534-Panel.GBP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]
2018-04-11 trying to figure out the read
    button read works ok first do a mask
    value & PIN6
    THEN DO a shift. is this the best way to do that?
2018-04-12 basic functionality
    can set a pin as input output
    can read inputs
    can set output as high or low
    it appears to be working well for pins 1 through 8!
    should probably think about making the silk screen and the coded pins match, ie there is no pin 8 but pin 7 and there is a pin0 in silk but not a pin0 in the code.
2018-04-17 made better examples
    trimmed the exmaples for writing and reading a gpio pin,
    need to do more testing for the interrupt example
2018-04-24 Updated the examples
    Cleaned up the examples, made the suggested changes from code review, implemented a way to identify which pins triggered the interrupt.
    [Qwiic_TCA9534.brd, Qwiic_TCA9534.sch]
2018-04-24 added addresses
    cleaned up schematic and added addresses.
    [Qwiic_GPIO.brd, Qwiic_GPIO.sch]
2020-01-29 Updated PCB with latch terminals and buzzard labels
    [Qwiic_GPIO.GBL, Qwiic_GPIO.GBO, Qwiic_GPIO.GBS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]
2020-01-30 Fixed routing and silk issues. Ready to order rev X02
    [Qwiic_GPIO.brd, Qwiic_GPIO.sch]
2020-01-30 Change silk to table
    [Qwiic_GPIO.brd, Qwiic_GPIO.sch]
2020-01-31 Panel/production files
    [Qwiic_GPIO-Panel.GBL, Qwiic_GPIO-Panel.GBO, Qwiic_GPIO-Panel.GBS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]
2020-02-19 Added missing product ID's
    [Qwiic_GPIO.brd, Qwiic_GPIO.sch]
2020-03-02 Got rid of old/non-relevant files, created .zip and schematic for product page, moved test sketch to hardware folder
    [Qwiic_GPIO.GBL, Qwiic_GPIO.GBO, Qwiic_GPIO.GBS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]
2020-03-13 Added PWR LED, made labels larger
    [Qwiic_GPIO.brd, Qwiic_GPIO.sch]
2020-03-13 Generated new panel file
    [Qwiic_GPIO-Panel.GBL, Qwiic_GPIO-Panel.GBO, Qwiic_GPIO-Panel.GBP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]
2020-03-25 Re-generated schematic .pdf with PWR LED
2020-04-06 Update SKU for new version of board

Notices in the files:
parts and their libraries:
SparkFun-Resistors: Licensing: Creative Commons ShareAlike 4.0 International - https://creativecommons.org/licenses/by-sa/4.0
